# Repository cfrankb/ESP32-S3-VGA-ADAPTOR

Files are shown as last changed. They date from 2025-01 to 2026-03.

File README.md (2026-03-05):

# Architectural Shift

Implementing a discrete DAC R-2R allows for full control over the signal chain and demonstrates the ability to interface digital MCUs with legacy analog standards without relying on specialized external ICs

# Encoding

Colors are encoded as unsigned 16bits integer (B5G6R5).

The five (5) lowest bits are red and in accending order of brigtness. The next six (6) bits are green and the last five (5) bits are blue.

# Schematic

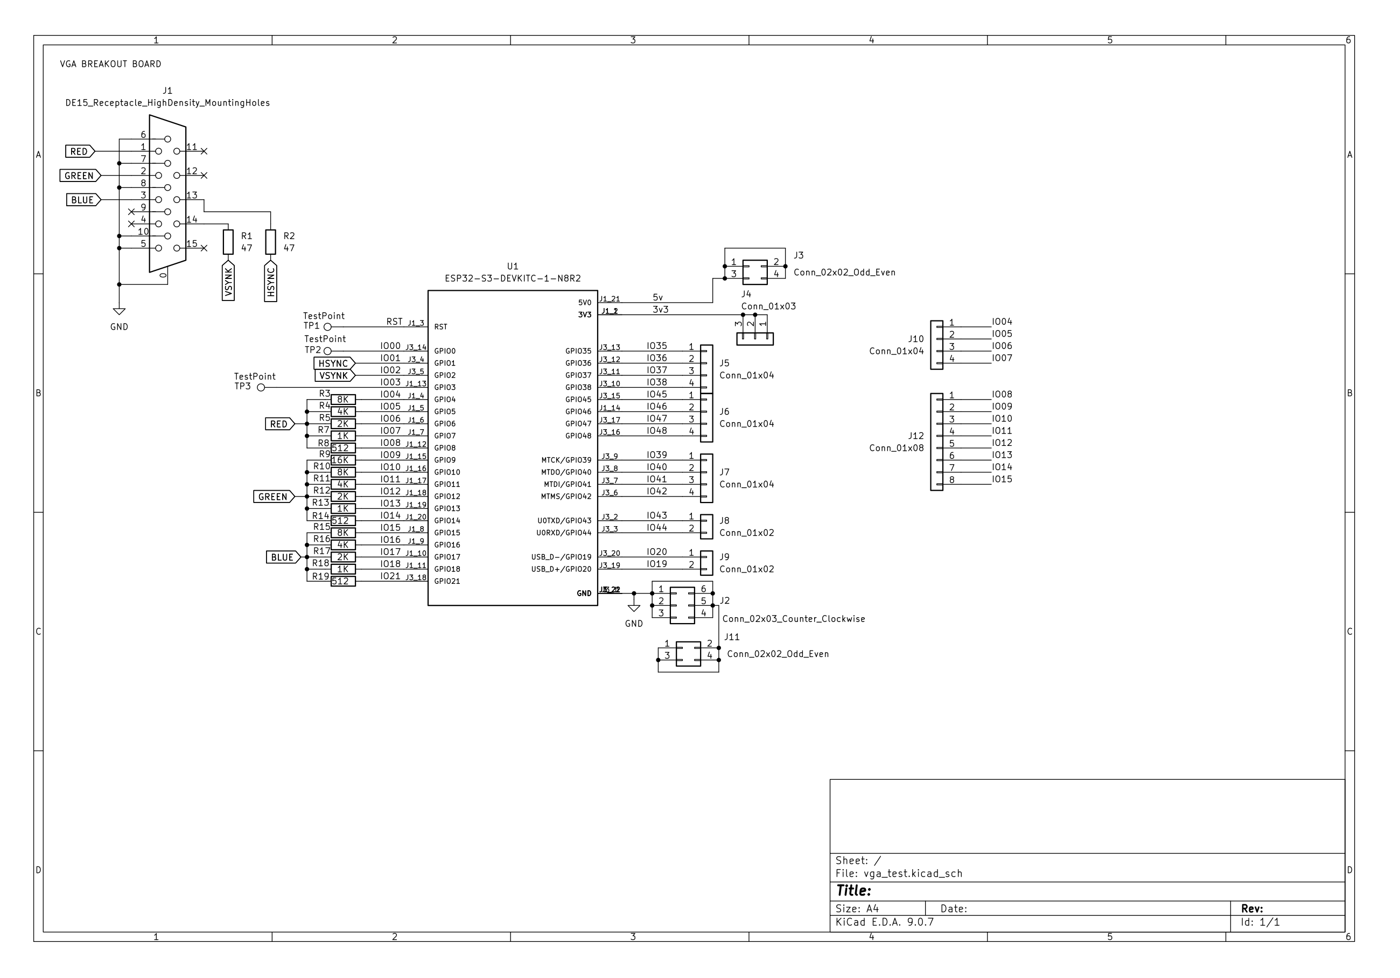
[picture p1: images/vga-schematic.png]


# Hardware

## ESP32-S3

Recommended ESP32S3 DevKit.

https://vi.aliexpress.com/item/1005006418608267.html

## Dupont cables

https://www.aliexpress.com/item/1005004611997111.html

## VGA Adaptor

An adaptor is needed to communicate with the VGA Hardware.

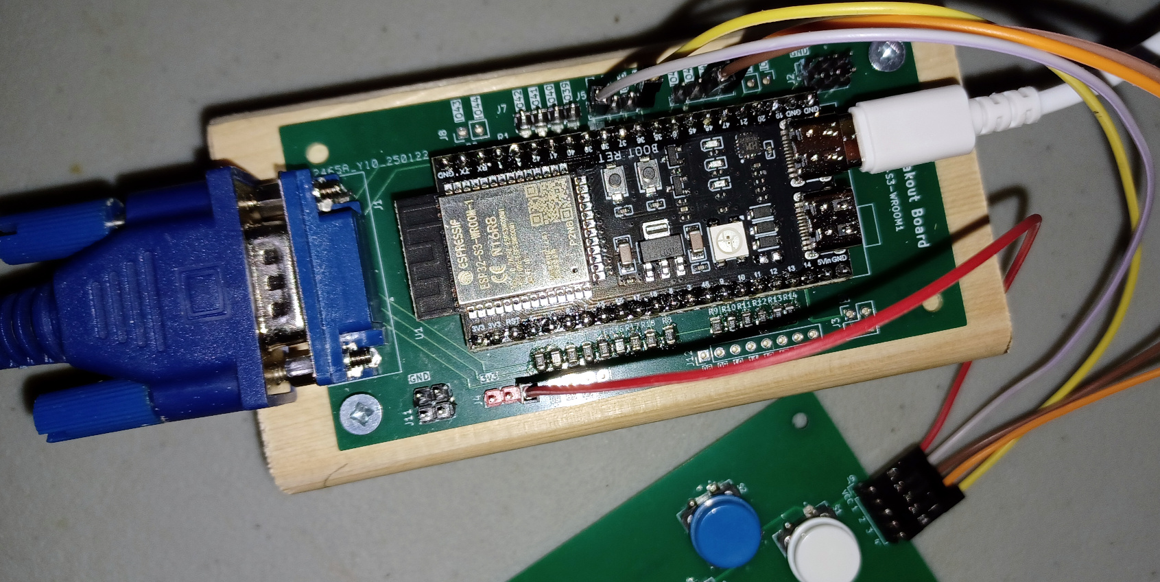
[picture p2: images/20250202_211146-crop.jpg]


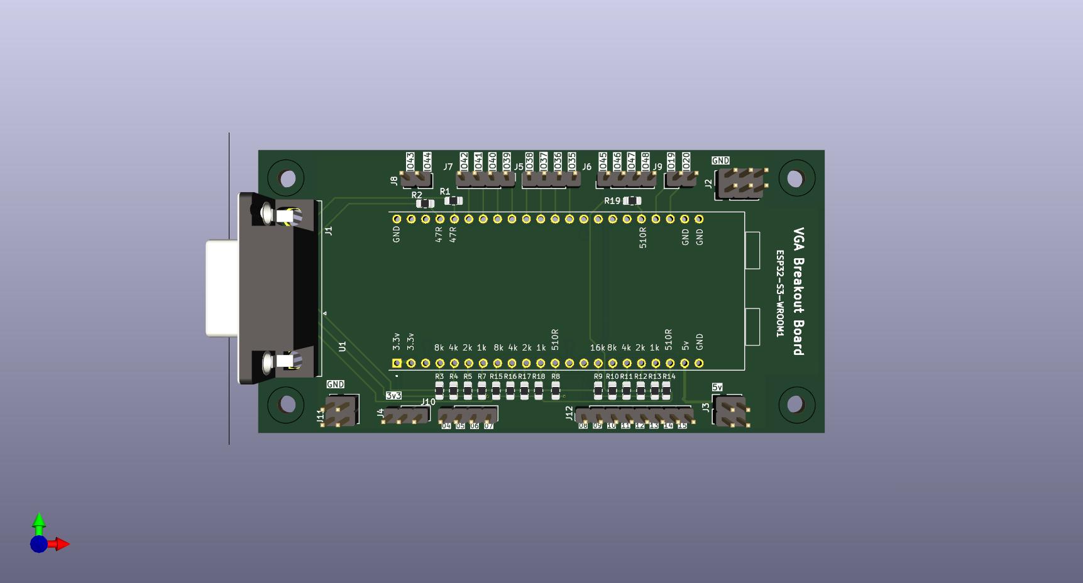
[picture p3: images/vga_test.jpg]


### Manually assembled

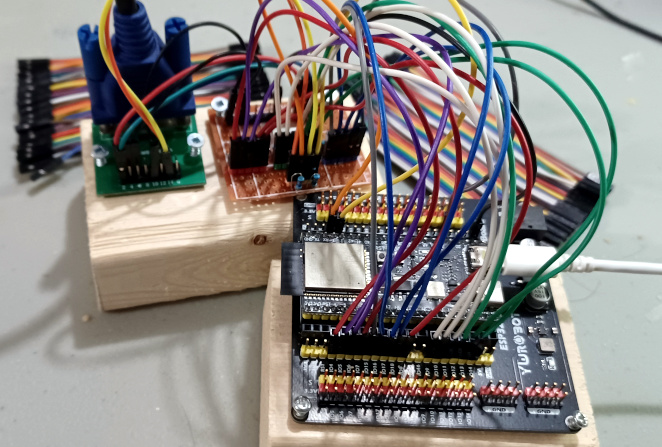
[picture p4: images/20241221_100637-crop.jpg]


Create a resistor ladder wire. Connect all the pins of the same color together.

| GPIO Pin | Role  | Resistor | VGA Pin |
| --- | ----- | --- | --- |
| 1 | hsync | 47R | 13 |
| 2 | vsync | 47R | 14 |
| 4 | red | 8k | 1 |
| 5 | red | 4k |
| 6 | red | 2k |
| 7 | red | 1k |
| 8 | red | 512R |
| 9 | green | 16k  * | 2 |
| 10 | green | 8k |
| 11 | green | 4k |
| 12 | green | 2k |
| 13 | green | 1k |
| 14 | green | 512R |
| 15 | blue  | 8k | 3 |
| 16 | blue  | 4k |
| 17 | blue  | 2k |
| 18 | blue  | 1k |
| 21 | blue  | 512R |
| GND | - | - | 5, 10 |

\* If you don't have any 16k Resistor. You can use a similar value such as 20k. The smallest resistor is the most significant and should be roughtly ~500R or higher.

VGA Connector: [DB15 to Dip 2.54mm interface ](https://vi.aliexpress.com/item/1005005279582020.html)

## Demo Project

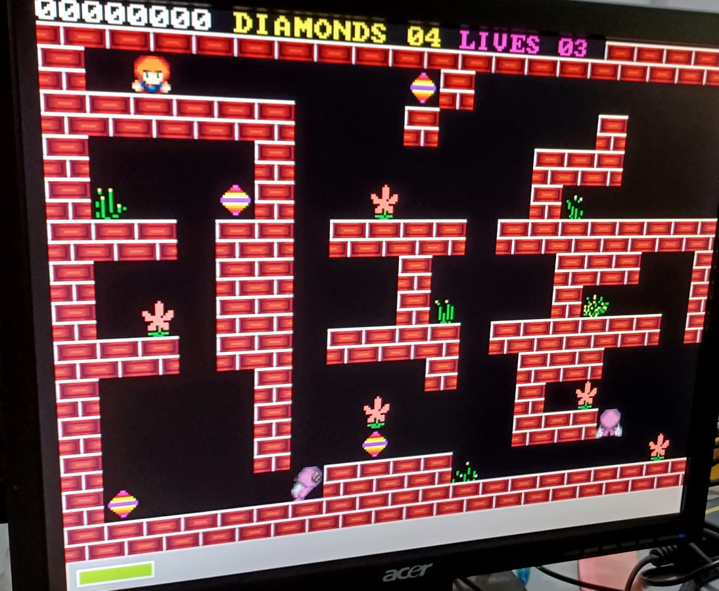
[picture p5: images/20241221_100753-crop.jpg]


Gameplay: https://www.youtube.com/watch?v=SPQwWkzFRpU

Source code: [cfrankb/ESP32-S3-VGA-CS3](https://github.com/cfrankb/ESP32-S3-VGA-CS3)

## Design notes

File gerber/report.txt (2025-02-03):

Plotted to '/home/cfrankb/kicad/projects/vga/vga_test4/gerber/vga_test-F_Cu.gbr'.
Plotted to '/home/cfrankb/kicad/projects/vga/vga_test4/gerber/vga_test-B_Cu.gbr'.
Plotted to '/home/cfrankb/kicad/projects/vga/vga_test4/gerber/vga_test-F_Paste.gbr'.
Plotted to '/home/cfrankb/kicad/projects/vga/vga_test4/gerber/vga_test-B_Paste.gbr'.
Plotted to '/home/cfrankb/kicad/projects/vga/vga_test4/gerber/vga_test-F_Silkscreen.gbr'.
Plotted to '/home/cfrankb/kicad/projects/vga/vga_test4/gerber/vga_test-B_Silkscreen.gbr'.
Plotted to '/home/cfrankb/kicad/projects/vga/vga_test4/gerber/vga_test-F_Mask.gbr'.
Plotted to '/home/cfrankb/kicad/projects/vga/vga_test4/gerber/vga_test-B_Mask.gbr'.
Plotted to '/home/cfrankb/kicad/projects/vga/vga_test4/gerber/vga_test-Edge_Cuts.gbr'.
Created Gerber job file '/home/cfrankb/kicad/projects/vga/vga_test4/gerber/vga_test-job.gbrjob'.
Info: Done.

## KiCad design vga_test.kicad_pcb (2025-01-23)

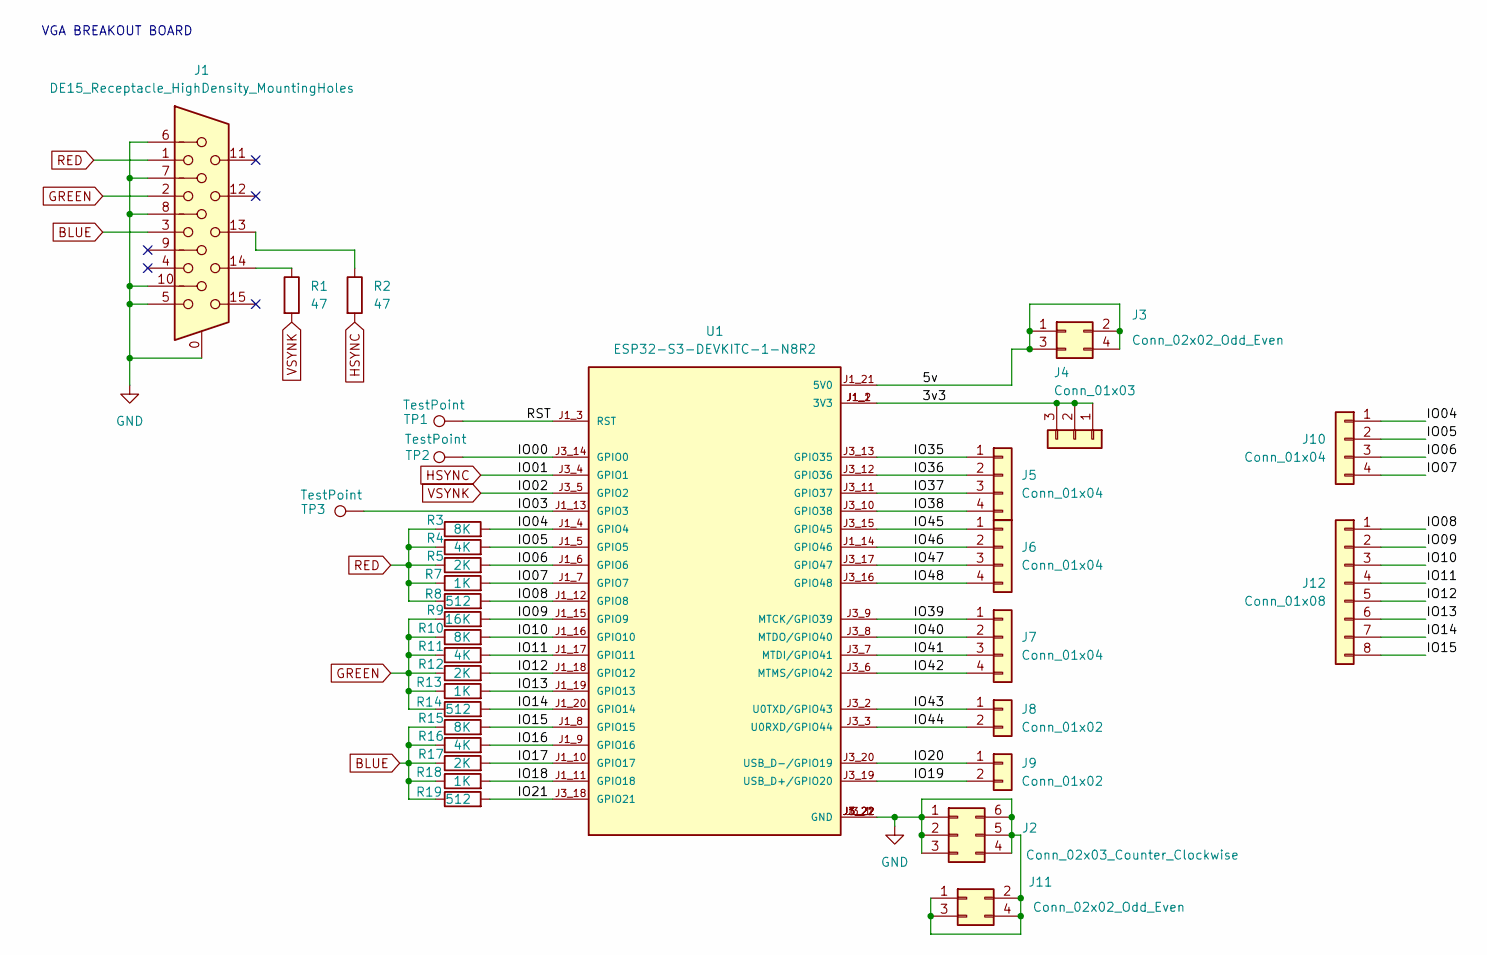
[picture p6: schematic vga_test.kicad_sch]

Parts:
J1: DE15_Receptacle_HighDensity_MountingHoles; DSUB-15-L77HDE15SD1CH4F
J2: Conn_02x03_Counter_Clockwise; PinHeader_2x03_P2.54mm_Vertical
J3, J11: Conn_02x02_Odd_Even; PinHeader_2x02_P2.54mm_Vertical
J4: Conn_01x03; PinHeader_1x03_P2.54mm_Vertical
J5, J6, J7, J10: Conn_01x04; PinHeader_1x04_P2.54mm_Vertical
J8, J9: Conn_01x02; PinHeader_1x02_P2.54mm_Vertical
J12: Conn_01x08; PinHeader_1x08_P2.54mm_Vertical
R1, R2: 47; R_0805_2012Metric_Pad1.20x1.40mm_HandSolder
R3, R10, R15: 8K; R_0805_2012Metric_Pad1.20x1.40mm_HandSolder
R4, R11, R16: 4K; R_0805_2012Metric_Pad1.20x1.40mm_HandSolder
R5, R12, R17: 2K; R_0805_2012Metric_Pad1.20x1.40mm_HandSolder
R7, R13, R18: 1K; R_0805_2012Metric_Pad1.20x1.40mm_HandSolder
R8, R14, R19: 512; R_0805_2012Metric_Pad1.20x1.40mm_HandSolder
R9: 16K; R_0805_2012Metric_Pad1.20x1.40mm_HandSolder
TP1, TP2, TP3: TestPoint; TestPoint_Pad_1.0x1.0mm
U1: ESP32-S3-DEVKITC-1-N8R2; ESP32-S3-WROOM1; PARTREV V1

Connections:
/3v3: J4.1, J4.2, J4.3, U1.J1_1 (3V3), U1.J1_2 (3V3)
/5v: J3.1, J3.2, J3.3, J3.4, U1.J1_21 (5V0)
/IO00: TP2.1, U1.J3_14 (GPIO0)
/IO03: TP3.1, U1.J1_13 (GPIO3)
/IO04: J10.1, R3.2, U1.J1_4 (GPIO4)
/IO05: J10.2, R4.2, U1.J1_5 (GPIO5)
/IO06: J10.3, R5.2, U1.J1_6 (GPIO6)
/IO07: J10.4, R7.2, U1.J1_7 (GPIO7)
/IO08: J12.1, R8.2, U1.J1_12 (GPIO8)
/IO09: J12.2, R9.2, U1.J1_15 (GPIO9)
/IO10: J12.3, R10.2, U1.J1_16 (GPIO10)
/IO11: J12.4, R11.2, U1.J1_17 (GPIO11)
/IO12: J12.5, R12.2, U1.J1_18 (GPIO12)
/IO13: J12.6, R13.2, U1.J1_19 (GPIO13)
/IO14: J12.7, R14.2, U1.J1_20 (GPIO14)
/IO15: J12.8, R15.2, U1.J1_8 (GPIO15)
/IO16: R16.2, U1.J1_9 (GPIO16)
/IO17: R17.2, U1.J1_10 (GPIO17)
/IO18: R18.2, U1.J1_11 (GPIO18)
/IO19: J9.2, U1.J3_19 (USB_D+/GPIO20)
/IO20: J9.1, U1.J3_20 (USB_D-/GPIO19)
/IO21: R19.2, U1.J3_18 (GPIO21)
/IO35: J5.1, U1.J3_13 (GPIO35)
/IO36: J5.2, U1.J3_12 (GPIO36)
/IO37: J5.3, U1.J3_11 (GPIO37)
/IO38: J5.4, U1.J3_10 (GPIO38)
/IO39: J7.1, U1.J3_9 (MTCK/GPIO39)
/IO40: J7.2, U1.J3_8 (MTDO/GPIO40)
/IO41: J7.3, U1.J3_7 (MTDI/GPIO41)
/IO42: J7.4, U1.J3_6 (MTMS/GPIO42)
/IO43: J8.1, U1.J3_2 (U0TXD/GPIO43)
/IO44: J8.2, U1.J3_3 (U0RXD/GPIO44)
/IO45: J6.1, U1.J3_15 (GPIO45)
/IO46: J6.2, U1.J1_14 (GPIO46)
/IO47: J6.3, U1.J3_17 (GPIO47)
/IO48: J6.4, U1.J3_16 (GPIO48)
/RST: TP1.1, U1.J1_3 (RST)
BLUE: J1.3, R15.1, R16.1, R17.1, R18.1, R19.1
GND: J1.0, J1.5, J1.6, J1.7, J1.8, J1.10, J2.1, J2.2, J2.3, J2.4, J2.5, J2.6, J11.1, J11.2, J11.3, J11.4, U1.J1_22 (GND), U1.J3_1 (GND), U1.J3_21 (GND), U1.J3_22 (GND)
GREEN: J1.2, R9.1, R10.1, R11.1, R12.1, R13.1, R14.1
HSYNC: R2.2, U1.J3_4 (GPIO1)
unnamed: J1.13, R2.1
unnamed: J1.14, R1.1
RED: J1.1, R3.1, R4.1, R5.1, R7.1, R8.1
VSYNK: R1.2, U1.J3_5 (GPIO2)

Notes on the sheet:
VGA BREAKOUT BOARD

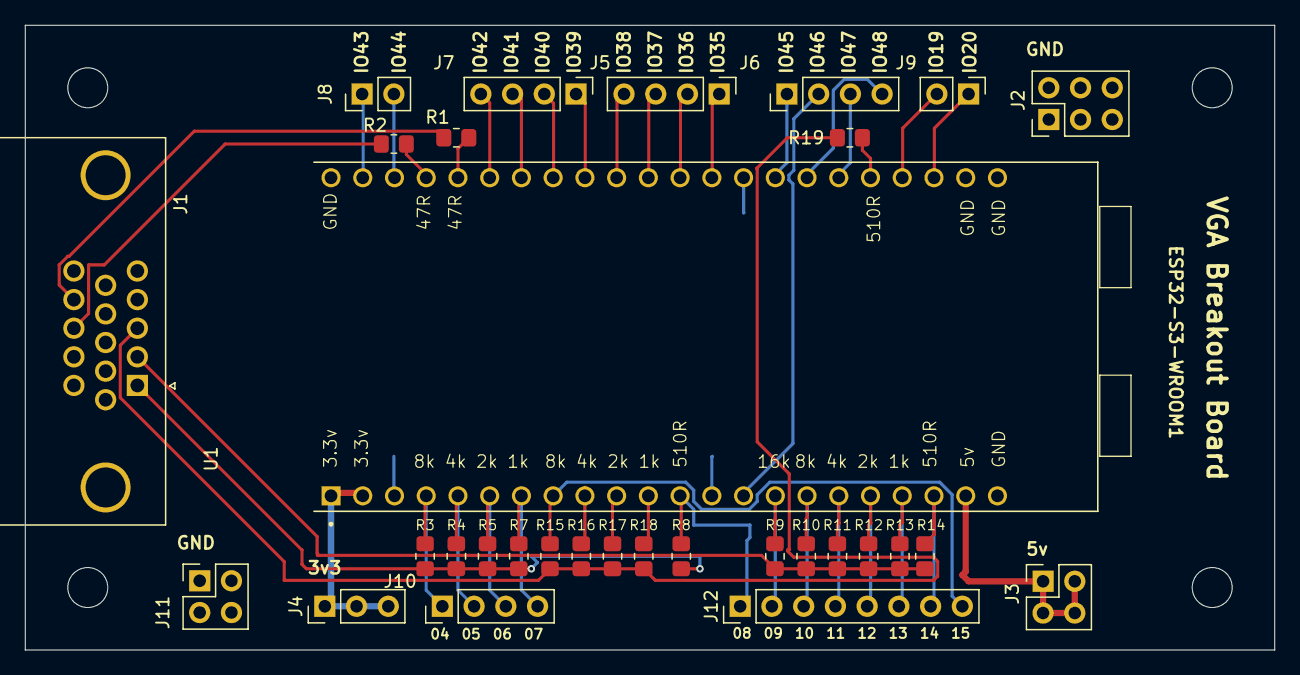
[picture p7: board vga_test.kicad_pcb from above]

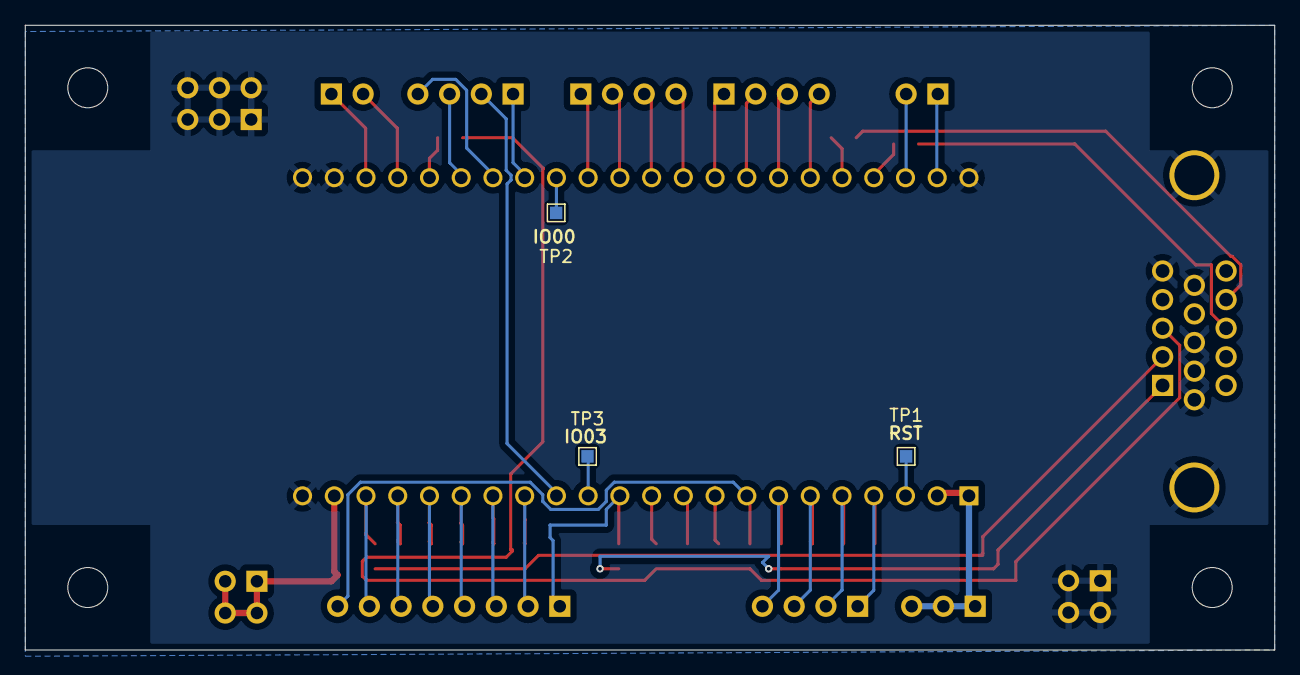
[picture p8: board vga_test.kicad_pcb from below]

Board: 2 copper layers, 100.0 x 50.0 mm, 38 parts (3 on the bottom side), 45 nets.

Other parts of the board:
H3, H3#2, H3#3, H3#4: MountingHole; MountingHole_3.2mm_M3

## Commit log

2025-02-03 added picture and gerber
    [vga_test-B_Cu.gbr, vga_test-B_Mask.gbr, vga_test-B_Paste.gbr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]
2025-02-03 added dsub15 footprint
2026-03-05 added schematic
2026-03-05 added more text
    [vga_test.kicad_sch]
